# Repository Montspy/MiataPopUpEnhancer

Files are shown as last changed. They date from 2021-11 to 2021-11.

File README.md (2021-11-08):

# MiataPopUpEnhancer
Plug and play module to add wink to NA Miata pop up headlights

Features targeted:
- [ ] Plug'n'play in harness (no cutting, soldering nonsense)
- [ ] Indepedent control of left and right headlight motor
- [ ] Execute movements sequences via short or long presses combo of the pop up button
- [ ] Maintain OEM function of the pop up button and the headlight switch
- [ ] Drag'n'drop programming (via USB Mass storage)
- [ ] TBD: Sleepy eyes
- [ ] TBD: Control and settings via app (BLE)



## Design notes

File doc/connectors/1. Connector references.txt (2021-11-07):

El-04  RETRACTABlE HEADLIGHT ACTUATOR LH
El-05  RETRACTABlE HEADLIGHT ACTUATOR RH
	TE Connectivity 881778-1 and 881779-1
		https://www.te.com/usa-en/product-881778-1.html
		https://www.te.com/usa-en/product-881779-1.html
E1-08 RETRACTABLE HEADLIGHT SWITCH
	??
		??

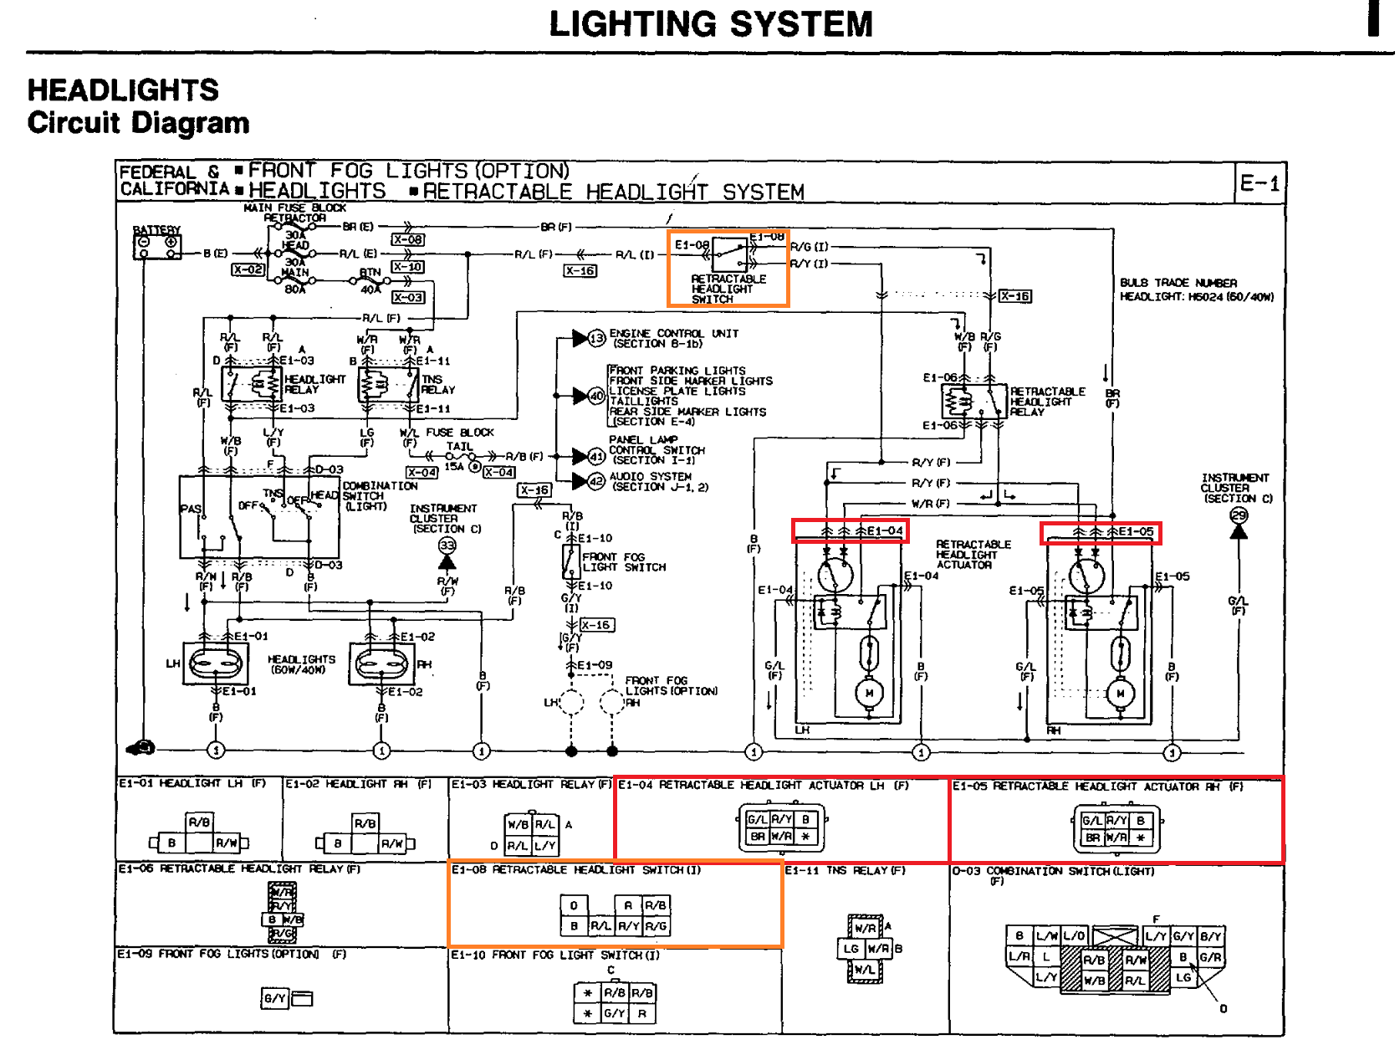
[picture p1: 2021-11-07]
doc/connectors/0. HEADLIGHTS Circuit Diagram.png

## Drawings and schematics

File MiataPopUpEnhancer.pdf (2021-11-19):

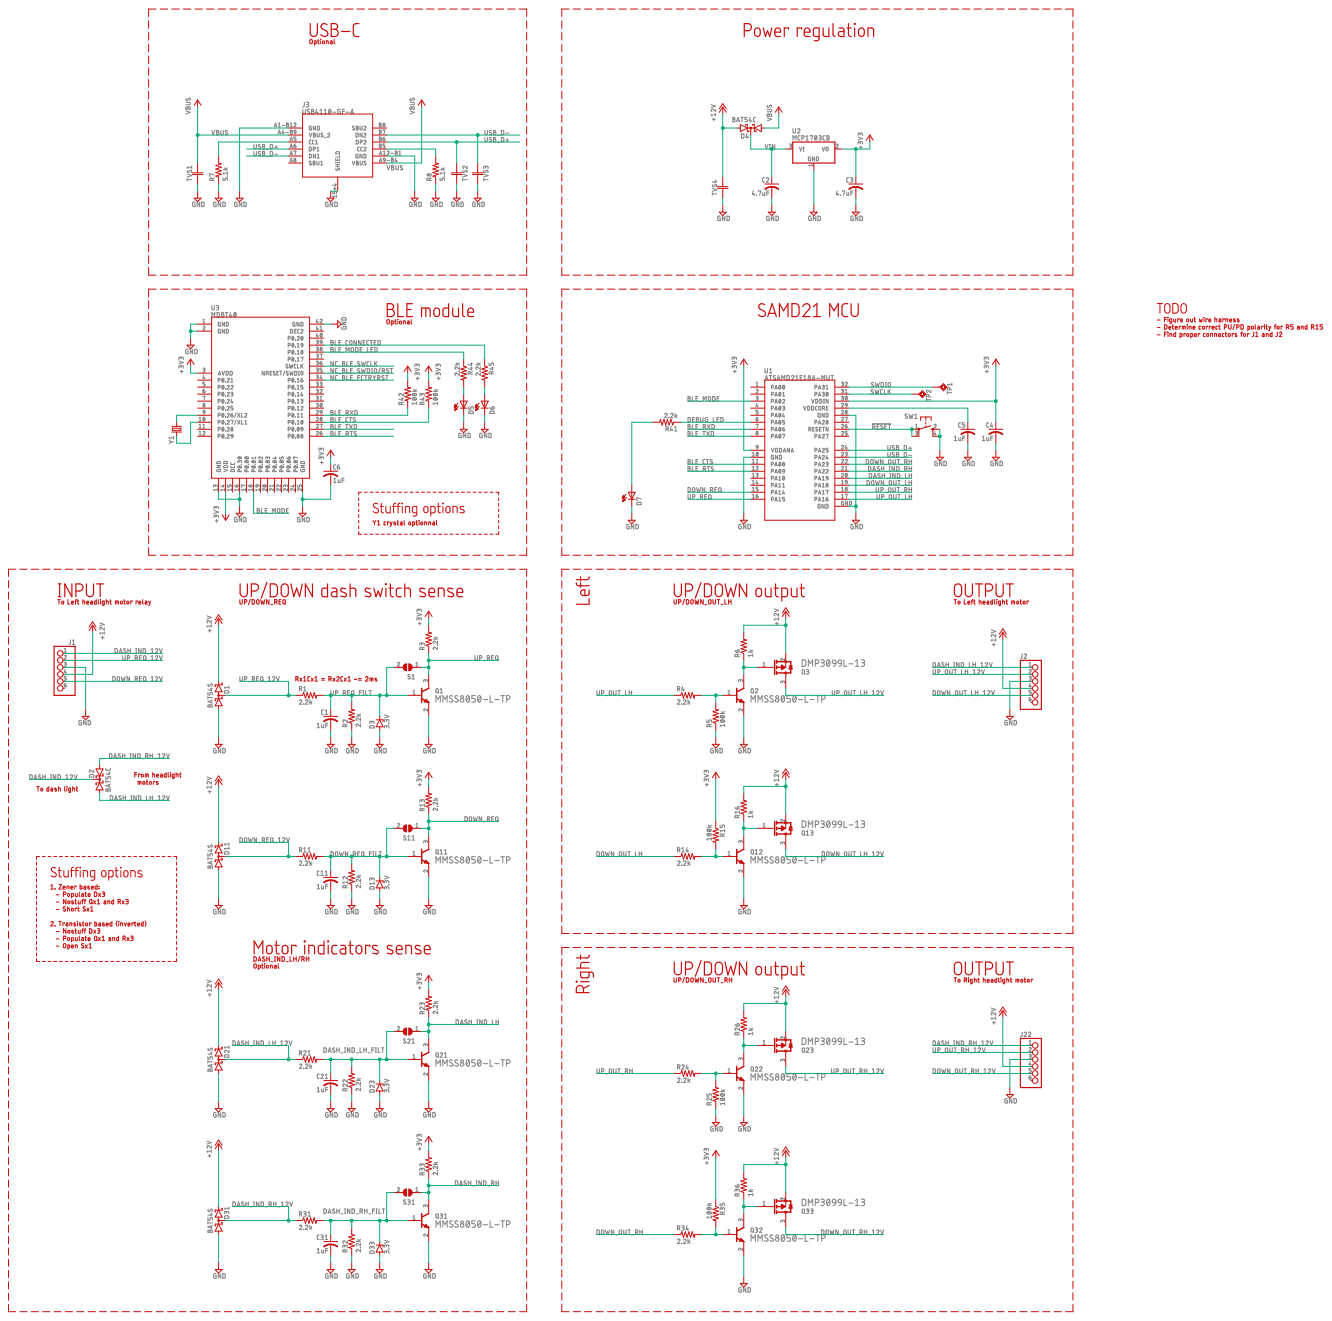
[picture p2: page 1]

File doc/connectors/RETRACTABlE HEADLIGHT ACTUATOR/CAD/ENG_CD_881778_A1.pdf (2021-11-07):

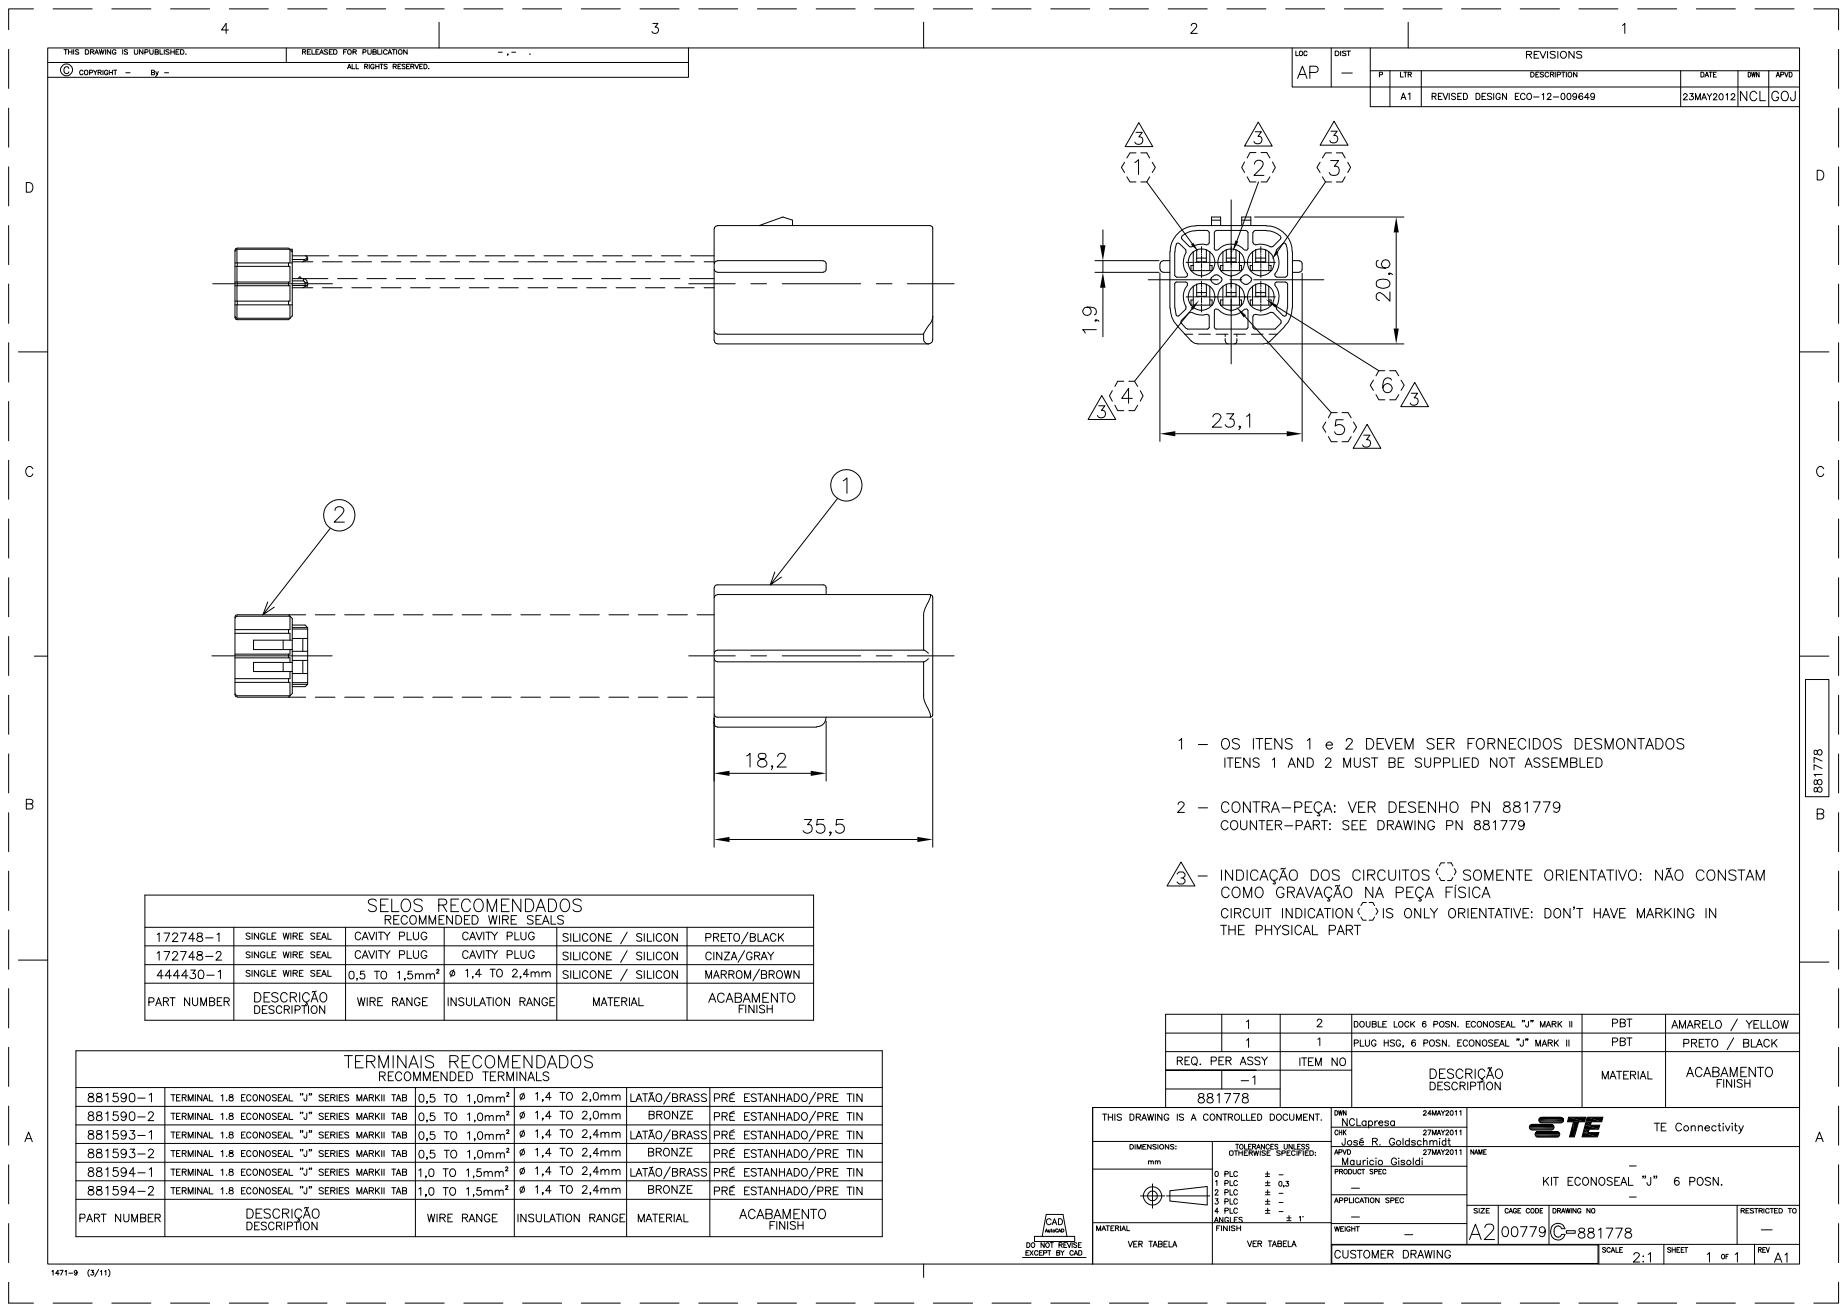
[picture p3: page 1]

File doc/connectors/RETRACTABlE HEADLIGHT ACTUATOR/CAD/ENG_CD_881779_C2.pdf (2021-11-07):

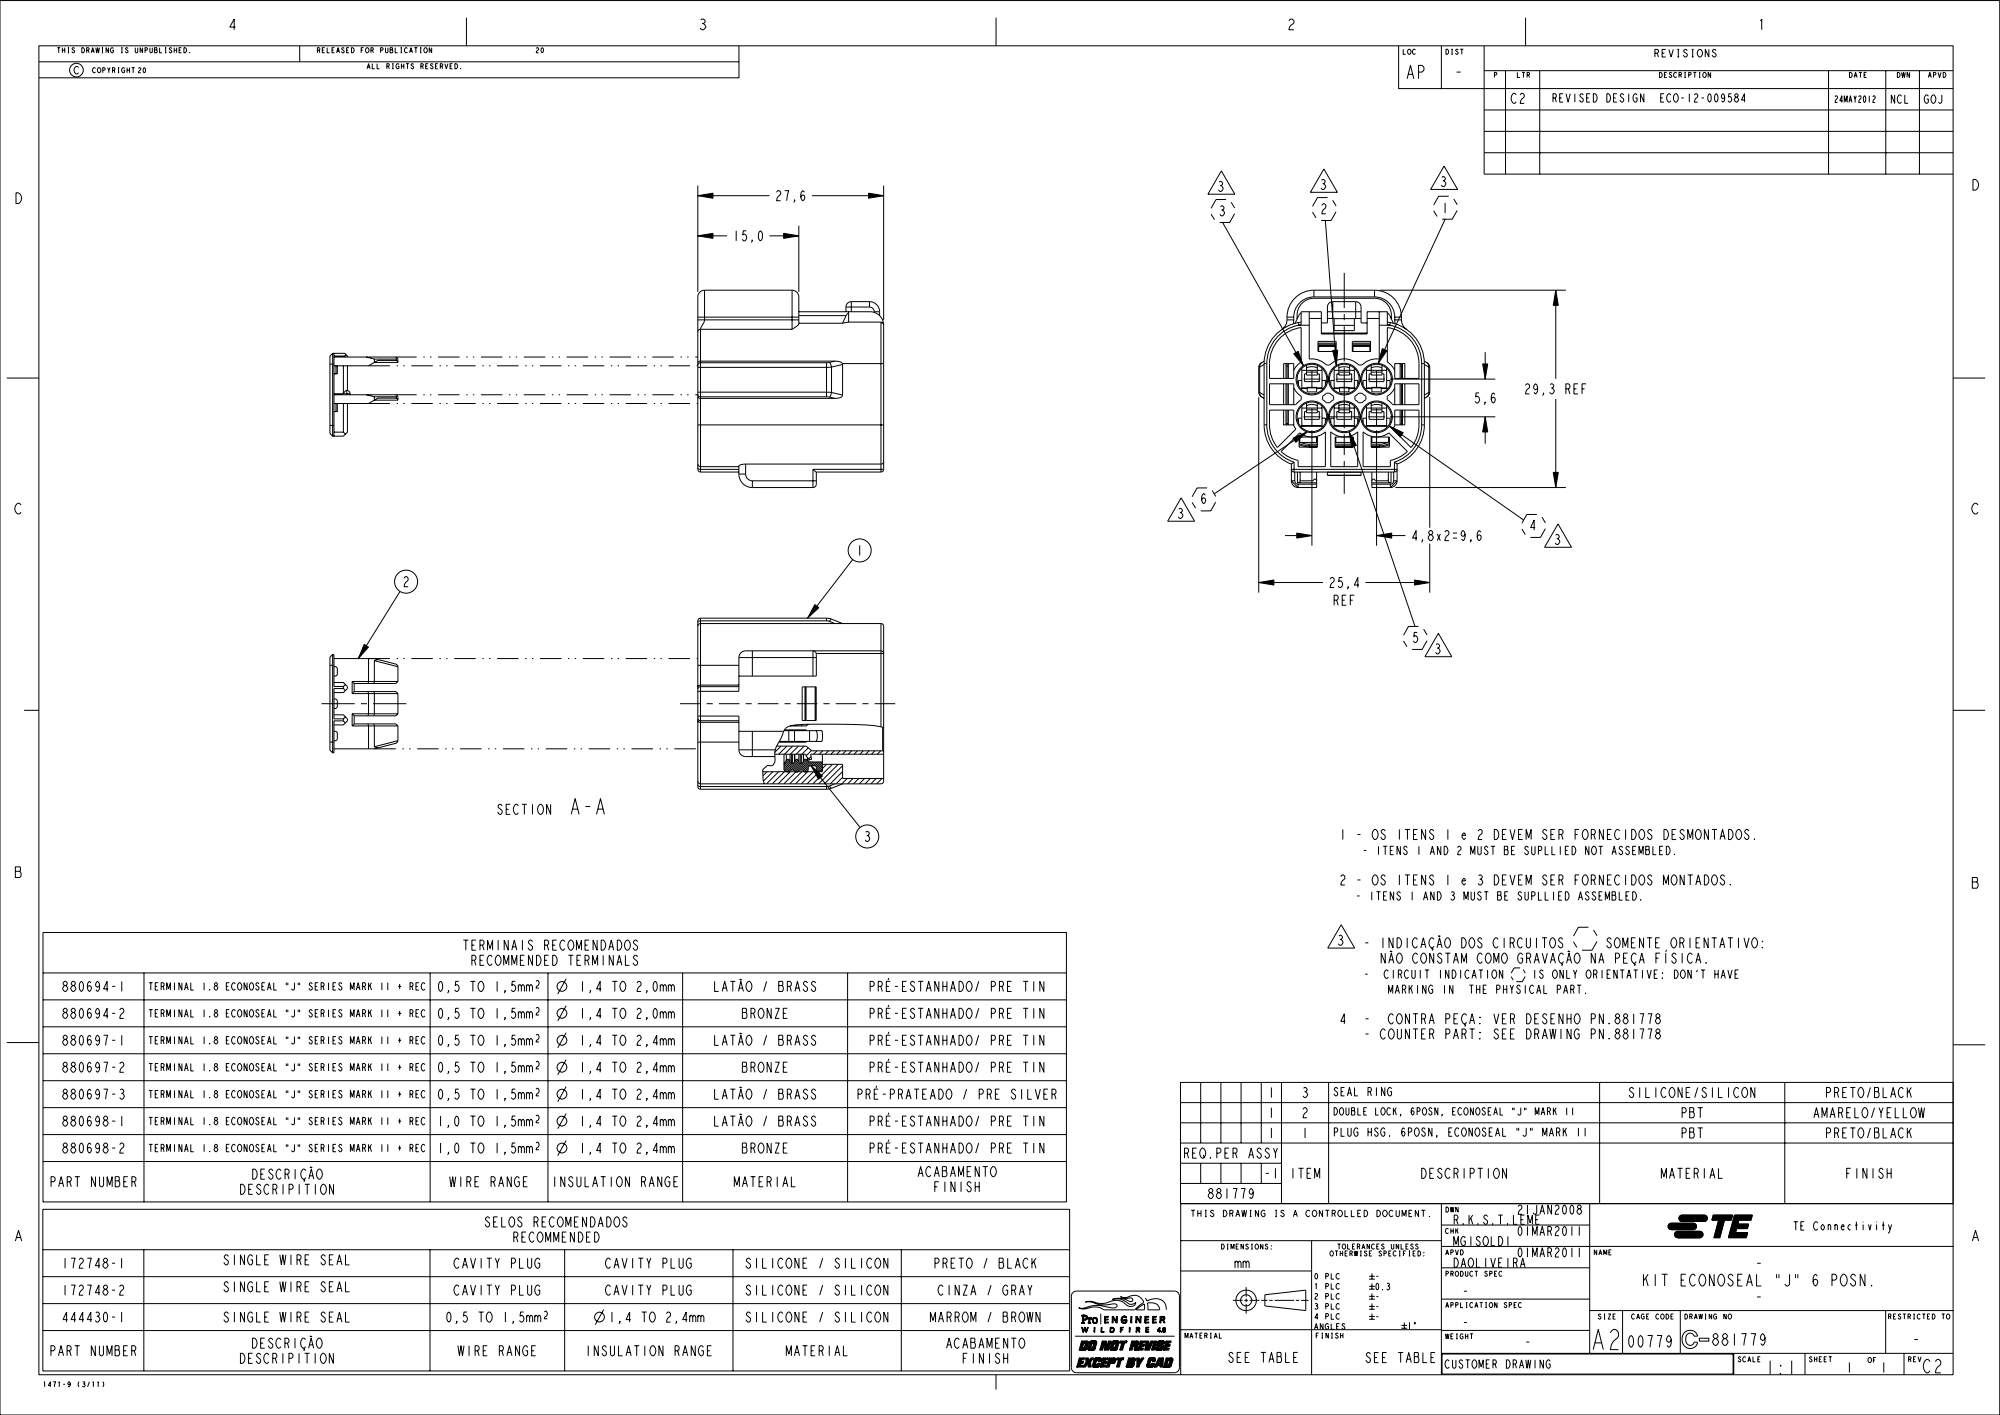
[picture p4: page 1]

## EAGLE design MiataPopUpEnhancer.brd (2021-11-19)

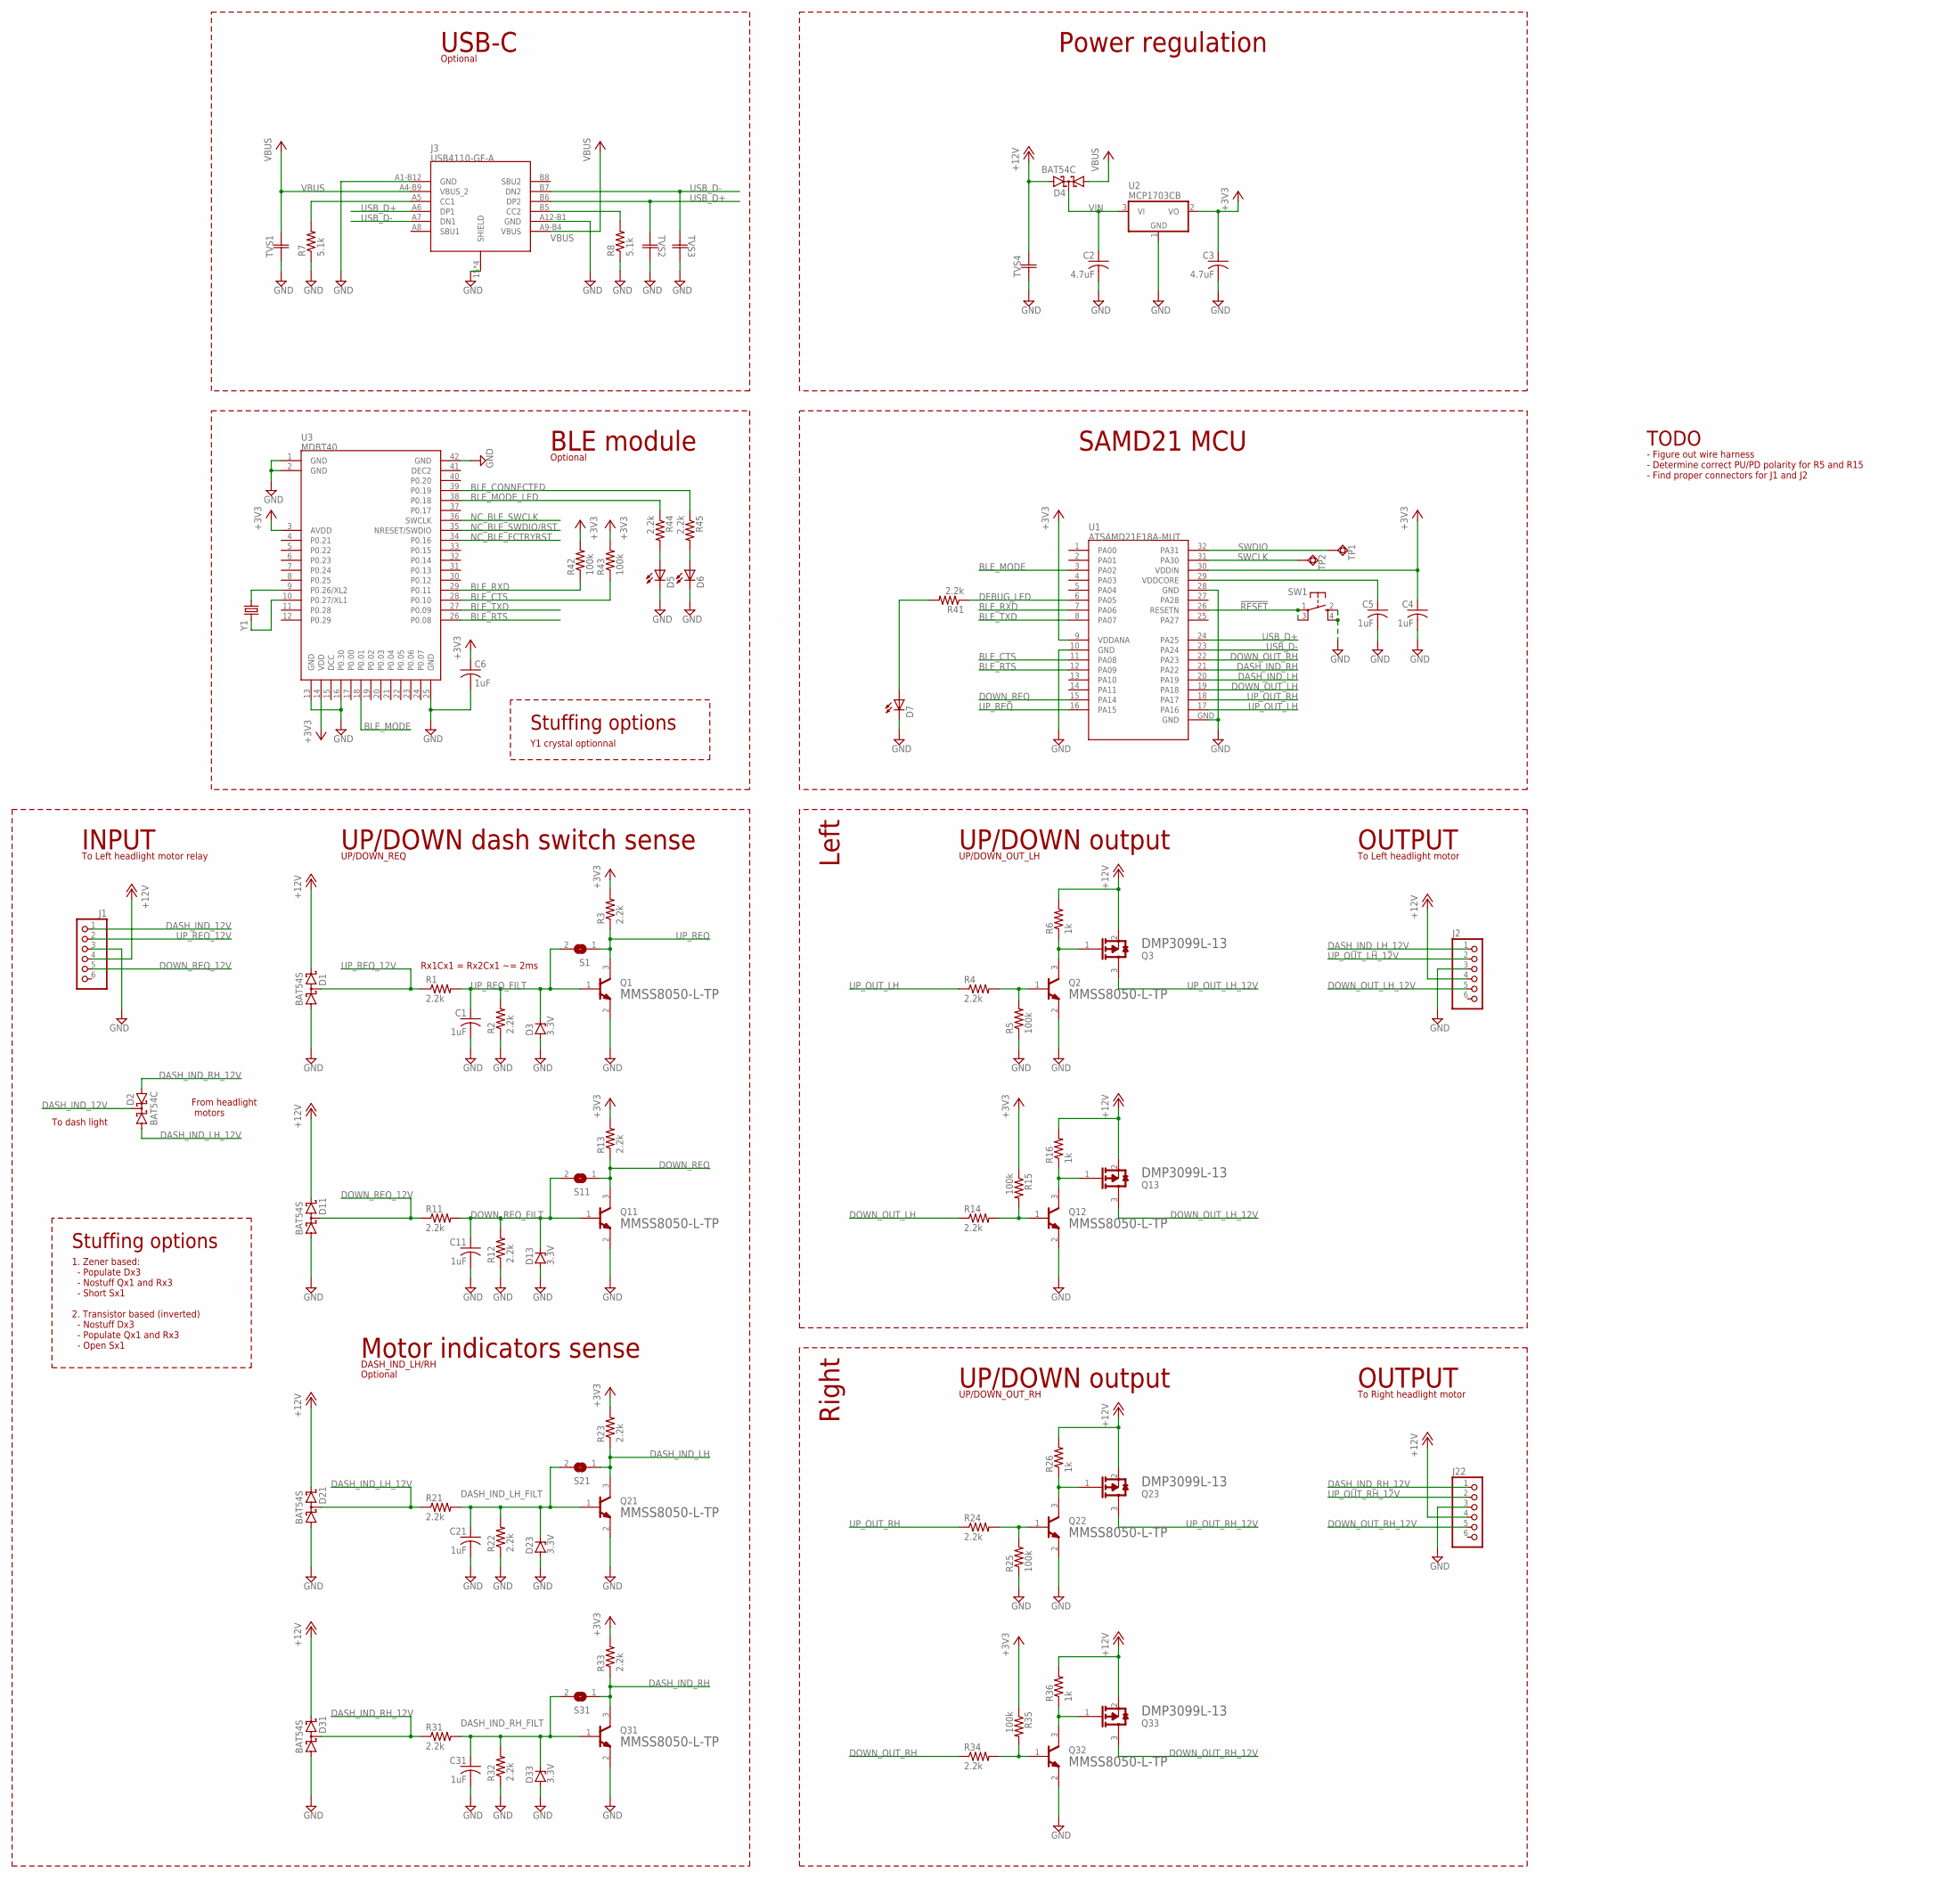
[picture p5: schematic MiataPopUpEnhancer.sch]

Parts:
C1, C4, C5, C6, C11, C21, C31: 1uF; C0603
C2: 4.7uF; C0603K
C3: 4.7uF; C0603
D1, D11, D21, D31: BAT54S; SOT23
D2, D4: BAT54C; SOT23
D3, D13, D23, D33: 3.3V; TO236
D5, D6, D7: LEDCHIPLED_0603; CHIPLED_0603
J1, J2, J22: PINHD-1X6LOCK; 1X06-BIGLOCK
J3: USB4110-GF-A; USB4110-GF-A_GCT
Q1, Q2, Q11, Q12, Q21, Q22, Q31, Q32: MICRO_COMMERCIAL_MMSS8050-L-TPMICRO_COMMERCIAL_MM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; MICRO_COMMERCIAL_MMSS8050-L-TP_0
Q3, Q13, Q23, Q33: DIODES_INC_DMP3099L-13DIODES_INC_DMP3099L-13_0_0; DIODES_INC_DMP3099L-13_0
R1, R2, R3, R4, R11, R12, R13, R14, R21, R22, R23, R24, R31, R32, R33, R34, R41, R44, R45: 2.2k; R0603
R5, R15, R25, R35, R42, R43: 100k; R0603
R6, R16, R26, R36: 1k; R0603
R7, R8: 5.1k; R0603
S1, S11, S21, S31: SJ
SW1: KMR2
TP1, TP2: TPSQB2,54; B2,54
TVS1, TVS2, TVS3, TVS4: ESDU02A5V5R17V; CAP_ESDU02_STP
U1: ATSAMD21E18A-MUT; QFN32
U2: MCP1703CB; SOT23
U3: MDBT40
Y1: ABS25-32.768KHZ-T; MM20SS

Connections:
!RESET: SW1.1, SW1.3 (P1), U1.26 (RESETN)
+3V3: C3.1, C4.1, C6.1, R3.2, R13.2, R15.1, R23.2, R33.2, R35.1, R42.2, R43.2, U1.9 (VDDANA), U1.30 (VDDIN), U2.2 (VO), U3.3 (AVDD), U3.14 (VDD)
+12V: D1.2 (C2), D4.2 (A2), D11.2 (C2), D21.2 (C2), D31.2 (C2), J1.4, J2.4, J22.4, Q3.2 (S), Q13.2 (S), Q23.2 (S), Q33.2 (S), R6.2, R16.2, R26.2, R36.2, TVS4.1
BLE_CONNECTED: R45.1, U3.39 (P0.19)
BLE_CTS: R43.1, U1.11 (PA08), U3.28 (P0.10)
BLE_MODE: U1.3 (PA02), U3.18 (P0.01)
BLE_MODE_LED: R44.1, U3.38 (P0.18)
BLE_RTS: U1.12 (PA09), U3.26 (P0.08)
BLE_RXD: R42.1, U1.7 (PA06), U3.29 (P0.11)
BLE_TXD: U1.8 (PA07), U3.27 (P0.09)
CC1: J3.A5 (CC1), R7.2
CC2: J3.B5 (CC2), R8.2
DASH_IND_12V: D2.3 (CC), J1.1
DASH_IND_LH: Q21.3 (C), R23.1, S21.1, U1.20 (PA19)
DASH_IND_LH_12V: D2.1 (A1), D21.3 (C1A2), J2.1, R21.1
DASH_IND_LH_FILT: C21.1, D23.C, Q21.1 (B), R21.2, R22.2, S21.2
DASH_IND_RH: Q31.3 (C), R33.1, S31.1, U1.21 (PA22)
DASH_IND_RH_12V: D2.2 (A2), D31.3 (C1A2), J22.1, R31.1
DASH_IND_RH_FILT: C31.1, D33.C, Q31.1 (B), R31.2, R32.2, S31.2
DEBUG_LED: R41.1, U1.6 (PA05)
DOWN_OUT_LH: R14.1, U1.19 (PA18)
DOWN_OUT_LH_12V: J2.5, Q13.3 (D)
DOWN_OUT_RH: R34.1, U1.22 (PA23)
DOWN_OUT_RH_12V: J22.5, Q33.3 (D)
DOWN_REQ: Q11.3 (C), R13.1, S11.1, U1.15 (PA14)
DOWN_REQ_12V: D11.3 (C1A2), J1.5, R11.1
DOWN_REQ_FILT: C11.1, D13.C, Q11.1 (B), R11.2, R12.2, S11.2
GND: C1.2, C2.2, C3.2, C4.2, C5.2, C6.2, C11.2, C21.2, C31.2, D1.1 (A1), D3.A, D5.C, D6.C, D7.C, D11.1 (A1), D13.A, D21.1 (A1), D23.A, D31.1 (A1), D33.A, J1.3, J2.3, J3.15 (SHIELD), J3.16 (SHIELD), J3.17 (SHIELD), J3.18 (SHIELD), J3.A1-B12 (GND), J3.A12-B1 (GND), J22.3, Q1.2 (E), Q2.2 (E), Q11.2 (E), Q12.2 (E), Q21.2 (E), Q22.2 (E), Q31.2 (E), Q32.2 (E), R2.1, R5.1, R7.1, R8.1, R12.1, R22.1, R25.1, R32.1, SW1.2 (S), SW1.4 (S1), TVS1.1, TVS2.1, TVS3.1, TVS4.2, U1.10 (GND), U1.28 (GND), U1.GND, U2.1 (GND), U3.1 (GND), U3.2 (GND), U3.13 (GND), U3.16 (P0.30), U3.25 (GND), U3.42 (GND)
unnamed: Q12.3 (C), Q13.1 (G), R16.1
unnamed: Q2.3 (C), Q3.1 (G), R6.1
unnamed: Q12.1 (B), R14.2, R15.2
unnamed: Q2.1 (B), R4.2, R5.2
unnamed: Q22.3 (C), Q23.1 (G), R26.1
unnamed: Q22.1 (B), R24.2, R25.2
unnamed: Q32.3 (C), Q33.1 (G), R36.1
unnamed: Q32.1 (B), R34.2, R35.2
unnamed: D5.A, R44.2
unnamed: D6.A, R45.2
unnamed: D7.A, R41.2
NC_BLE_FCTRYRST: U3.34 (P0.16)
NC_BLE_SWCLK: U3.36 (SWCLK)
NC_BLE_SWDIO/RST: U3.35 (NRESET/SWDIO)
SWCLK: TP2.TP, U1.31 (PA30)
SWDIO: TP1.TP, U1.32 (PA31)
UP_OUT_LH: R4.1, U1.17 (PA16)
UP_OUT_LH_12V: J2.2, Q3.3 (D)
UP_OUT_RH: R24.1, U1.18 (PA17)
UP_OUT_RH_12V: J22.2, Q23.3 (D)
UP_REQ: Q1.3 (C), R3.1, S1.1, U1.16 (PA15)
UP_REQ_12V: D1.3 (C1A2), J1.2, R1.1
UP_REQ_FILT: C1.1, D3.C, Q1.1 (B), R1.2, R2.2, S1.2
USB_D+: J3.A6 (DP1), J3.B6 (DP2), TVS2.2, U1.24 (PA25)
USB_D-: J3.A7 (DN1), J3.B7 (DN2), TVS3.2, U1.23 (PA24)
VBUS: D4.1 (A1), J3.A4-B9 (VBUS_2), J3.A9-B4 (VBUS), TVS1.2
VDDCORE: C5.1, U1.29 (VDDCORE)
VIN: C2.1, D4.3 (CC), U2.3 (VI)
XL1: U3.10 (P0.27/XL1), Y1.4 (2)
XL2: U3.9 (P0.26/XL2), Y1.1

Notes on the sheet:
INPUT
OUTPUT
UP/DOWN dash switch sense
UP/DOWN output
Rx1Cx1 = Rx2Cx1 ~= 2ms
BLE module
SAMD21 MCU
To Left headlight motor relay
To Left headlight motor
Optional
TODO
- Figure out wire harness - Determine correct PU/PD polarity for R5 and R15 - Find proper connectors for J1 and J2
Stuffing options
1. Zener based: - Populate Dx3 - Nostuff Qx1 and Rx3 - Short Sx1 2. Transistor based (inverted) - Nostuff Dx3 - Populate Qx1 and Rx3 - Open Sx1
Left
To Right headlight motor
Right
From headlight motors
To dash light
Power regulation
USB-C
Motor indicators sense
UP/DOWN_REQ
DASH_IND_LH/RH
UP/DOWN_OUT_LH
UP/DOWN_OUT_RH
Y1 crystal optionnal

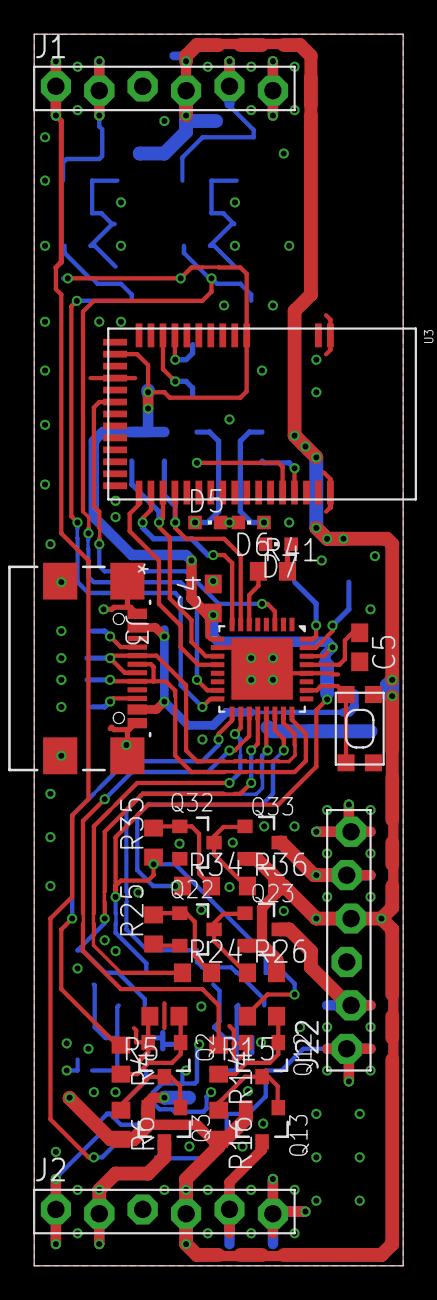
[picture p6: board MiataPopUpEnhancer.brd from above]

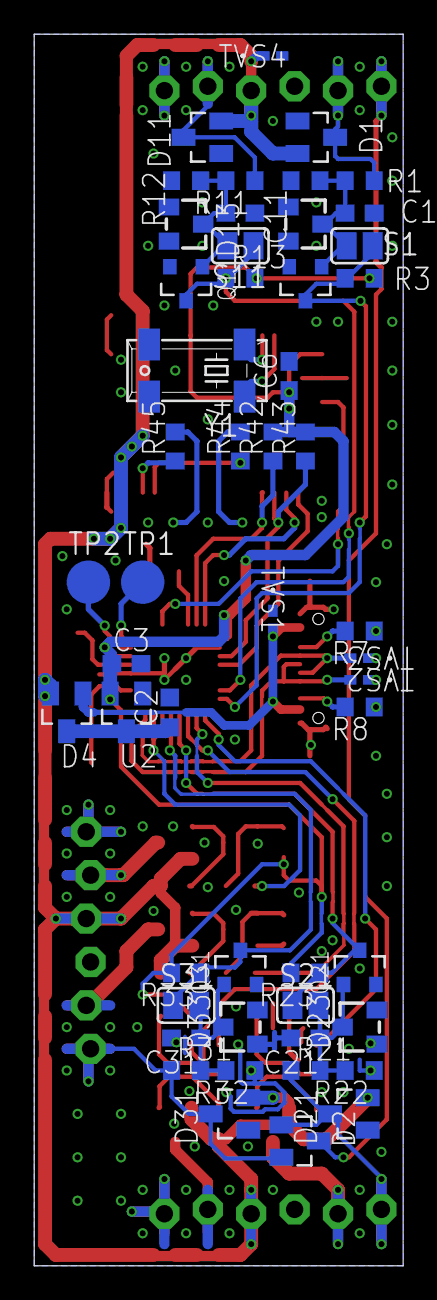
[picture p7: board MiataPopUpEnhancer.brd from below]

Board: 2 copper layers, 21.6 x 72.1 mm, 84 parts (51 on the bottom side), 55 nets.

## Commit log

2021-11-07 First darft of schematic
    [MiataPopUpEnhancer.sch]
2021-11-07 Adds connectors documentation
2021-11-08 Adds BLE module Adds Motor indicator sense circuitry Simplifies INPUT circuitry for UP/DOWN requests Adds circuit protections
    [MiataPopUpEnhancer.sch]
2021-11-17 Adds first draft of board file. Updates USBC receptable footprint Minor corrections to schematic
    [MiataPopUpEnhancer.brd, MiataPopUpEnhancer.sch]
2021-11-18 Continues routing and cleanup of south end of board
    [MiataPopUpEnhancer.brd, MiataPopUpEnhancer.sch]
2021-11-19 First complete layout. Still using headers for connectors
    [MiataPopUpEnhancer.brd, MiataPopUpEnhancer.sch]

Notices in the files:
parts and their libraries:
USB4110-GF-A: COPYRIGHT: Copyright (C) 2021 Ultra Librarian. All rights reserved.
